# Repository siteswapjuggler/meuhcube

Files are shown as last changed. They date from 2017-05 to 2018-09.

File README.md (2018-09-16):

# The MeuhCube project

The MeuhCube is an Open Source 7x7x7 LED cube project based on Arduino Mega 2560. It aims to provide any needed resources to create your own cube, including the electronic schematics, a laser cutted case and the firmware.

A MeuhCube can basically display embedded animations with the Arduino sketch or be driven over USB by any smart device like a computer, a Raspberry Pi or a smartphone.

The Arduino sketch also exposes a serial API over USB that can be implemented by some remote programs.

## What can I find in this repository?

There is some folders categorizing the resources:

  * **hardware:** Contains a bill of materials you'll need to buy, the electronic schematics, a laser cutted case and some 3D printable tools that will help you in you task
  * **software:** Contains the Arduino firmware and a young simulator, all you need to start!

You'll find more informations in the readme file of each folder.

## Remote clients over USB

You can drive a cube over USB with one of the clients in the **software** folder:

  * a Max/MSP sketch
  * a Proccesing library and simulator
  * a Python Module in Progress
  
You can also use this clients under developpement : 
  * [PLFM, a Python library for MeuhCube](https://gitlab.com/influencepc/Python-library-for-MeuhCube)

## External resources

We also post an additionnal documentation of this project in our local Fablab website :

  * 2016-01-15: [[fr] Meuh cube: Cube lumineux 7\*7\*7 Led V1](https://fablab.ledome.info/#!/projects/cube-lumineux-7-7-7-led)
  * 2016-09-01: [[fr] Meuhcube / cube à leds 7\*7\*7 v2](https://fablab.ledome.info/#!/projects/cube-lumineux-7-7-7-led-v2)

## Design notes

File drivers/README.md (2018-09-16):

# The driver folder

This folder contains the driver for the serial USB CH341 chipset used by some low cost Arduino Mega 2560s found on the net.

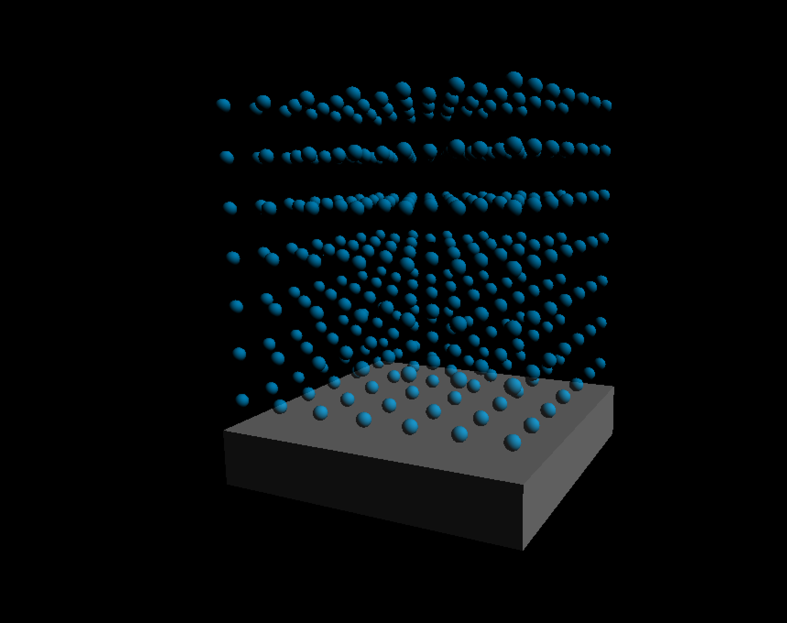
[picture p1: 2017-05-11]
software/processing/Cube simulator/cube_simulator.png

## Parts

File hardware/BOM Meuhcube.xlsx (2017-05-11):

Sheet: BOM
LISTE COMPOSANTS CUBE PCB
ref. Farnell | nom | specs | boitier | prix | nb | note | ou bien
1759415 | C3 | X5R / 6.3V / 22 uF | 0805 | 0.43 € | 1
2496834 | C1 | X7R / 6.3V / 0.1 uF | 0603 | 0.01 € | 1
2376912 | regulateur | ADP23001 | TSOT | 1.25 € | 1
1467689 | comparateur | TS391ILT | SOT-23-5 | 0.36 € | 1
2333955 | inductance | 4.7 uH |  | 0.74 € | 1
1843686 | D1 |  |  | 0.55 € | 1
1170937 | R1 | 31.6k | 0603 | 0.0012 € | 1
1170889 | R2 | 10.2k | 0603 | 0.01 € | 1
 | R3 |  | 603 |  | 7 |  | ????
1471048 | canal N |  |  | 0.15 € | 49
2317568 | transistor |  |  | 0.33 € | 7
2320833 | C2 | X5R / 25V / 10 uF | 0805 | 0.33 € | 1
1593494 | connecteur | 20 pin / femelle |  | 1.80 € | 1 |  | 1593503
2356147 | connecteur | 36 pin / male |  | 2.10 € | 1
2356160 | connecteur | 8 pin / male |  | 0.45 € | 5
1841229 | connecteur | 10 pin / male |  | 0.54 € | 1
1800872 | pieds | 3 mm / noir |  | 0.15 € | 4
- | PCB |  |  | 21.12 € | 1
 |  |  |  | 41.94 €
R2 - 3.1V | 9330453
R2 - 3V | 1170894

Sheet: Ports
PORT CONFIGURATION - 56 ports nécessaires pour les leds
D | A | USAGE | X | Y | Z
- | - | 3v3 |  |  |  | 22 ports à faire remonter
- | - | 5v
- | - | AREF
- | - | GND
- | - | IOREF
- | - | RESET
- | - | Vin
47 |  |  | 0 |  | 0
69 | 15 |  | 0 |  | 1
67 | 13 |  | 0 |  | 2
65 | 11 |  | 0 |  | 3
66 | 12 |  | 0 |  | 4
58 | 4 |  | 0 |  | 5
57 | 3 |  | 0 |  | 6
43 |  |  | 1 |  | 0
68 | 14 |  | 1 |  | 1
64 | 10 |  | 1 |  | 2
63 | 9 |  | 1 |  | 3
56 | 2 |  | 1 |  | 4
55 | 1 |  | 1 |  | 5
54 | 0 |  | 1 |  | 6
41 |  |  | 2 |  | 0
29 |  |  | 2 |  | 1
53 |  | SS
52 |  | SCK
51 |  | MOSI
50 |  | MISO
61 | 7 |  | 2 |  | 2
60 | 6 |  | 2 |  | 3
59 | 5 |  | 2 |  | 4
62 | 8 |  | 2 |  | 5
44 |  |  | 2 |  | 6
39 |  |  | 3 |  | 0
27 |  |  | 3 |  | 1
36 |  |  | 3 |  | 2
38 |  |  | 3 |  | 3
40 |  |  | 3 |  | 4
42 |  |  | 3 |  | 5
34 |  |  | 3 |  | 6
35 |  |  | 4 |  | 0
25 |  |  | 4 |  | 1
24 |  |  | 4 |  | 2
26 |  |  | 4 |  | 3
28 |  |  | 4 |  | 4
30 |  |  | 4 |  | 5
32 |  |  | 4 |  | 6
37 |  |  | 5 |  | 0
22 |  |  | 5 |  | 1
2 |  |  | 5 |  | 2
4 |  |  | 5 |  | 3
6 |  |  | 5 |  | 4
8 |  |  | 5 |  | 5
13 |  |  | 5 |  | 6
33 |  |  | 6 |  | 0
23 |  |  | 6 |  | 1
21 |  | SCL
20 |  | SDA
19 |  | RX1
18 |  | TX1
17 |  | RX2
16 |  | TX2
15 |  | RX3
14 |  | TX3
3 |  |  | 6 |  | 2
5 |  |  | 6 |  | 3
7 |  |  | 6 |  | 4
9 |  |  | 6 |  | 5
10 |  |  | 6 |  | 6
49 |  |  |  | 0
45 |  |  |  | 1
48 |  |  |  | 2
46 |  |  |  | 3
12 |  |  |  | 4
11 |  |  |  | 5
31 |  |  |  | 6
1 |  | TX0
0 |  | RX0

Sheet: Calcul régulateur
V out | R1/R2
2.9 | 2.625 |  | 3.098039216
 |  | 31.6 | 10.2 | 3.098039216
 |  | 31.6 | 11 | 2.872727273
 |  | 31.6 | 11.5 | 2.747826087
 |  | 31.6 | 10.2 | 3.098039216
 |  | 31.6 | 10.2 | 3.098039216
 |  | 31.6 | 10.2 | 3.098039216
 |  | 31.6 | 10.2 | 3.098039216
 |  | 31.6 | 10.2 | 3.098039216
 |  | 31.6 | 10.2 | 3.098039216
 |  | 31.6 | 10.2 | 3.098039216
 |  | 31.6 | 10.2 | 3.098039216
 |  | 31.6 | 10.2 | 3.098039216
 |  | 31.6 | 10.2 | 3.098039216

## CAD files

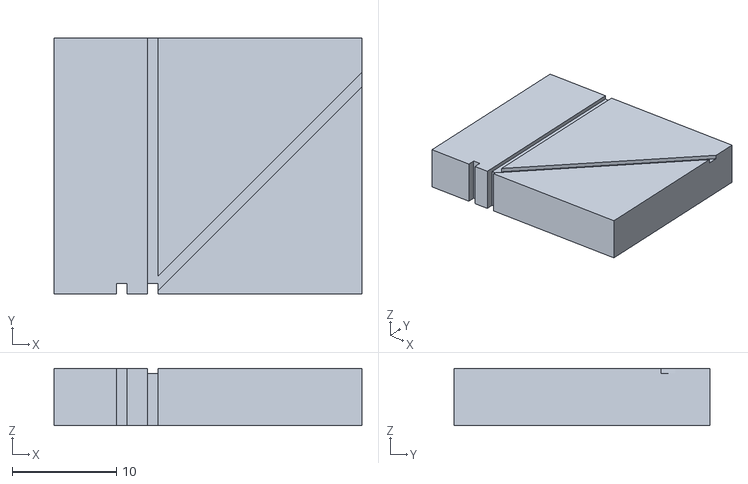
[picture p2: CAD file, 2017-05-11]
hardware/STL prints/1 x plieur_led2.stl
29.6 x 24.6 x 5.50

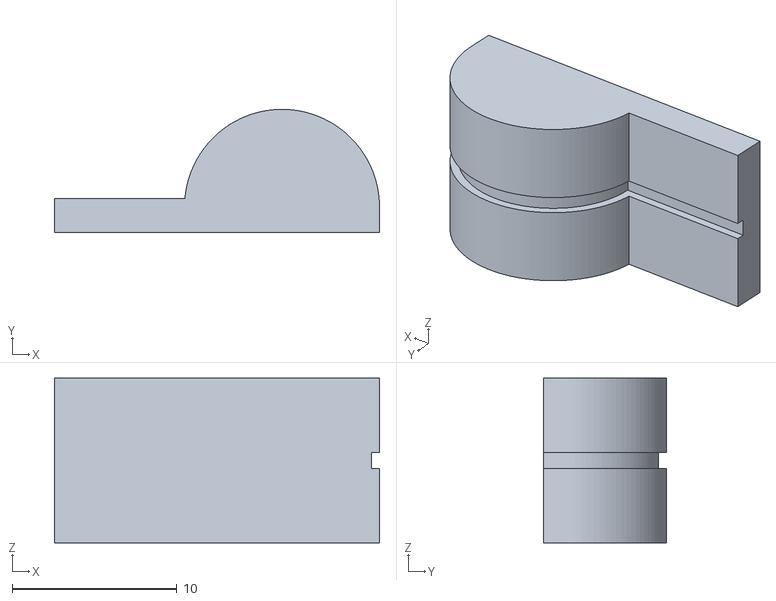
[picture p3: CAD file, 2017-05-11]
hardware/STL prints/1 x rond_led2_10mm.stl
19.7 x 7.48 x 10.0

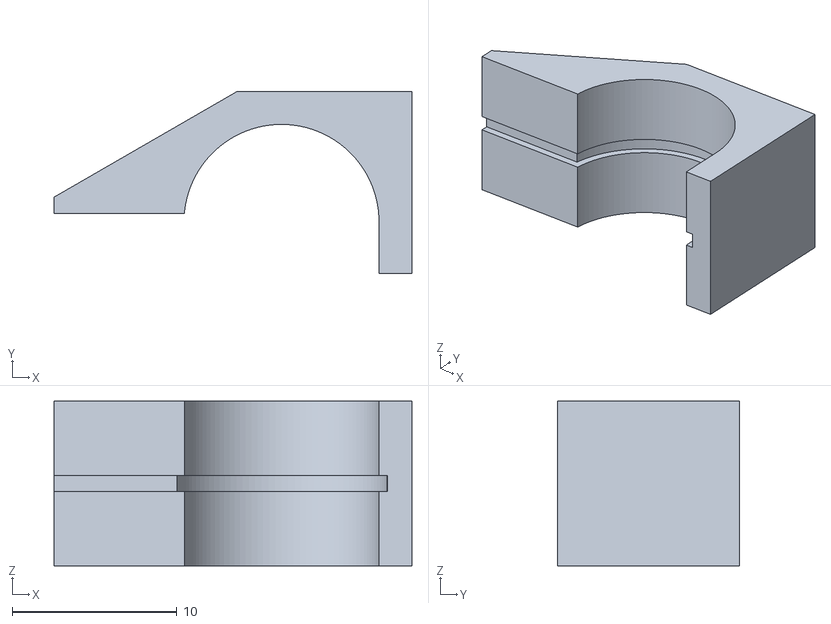
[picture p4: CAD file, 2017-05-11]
hardware/STL prints/1 x rond_led1_10mm.stl
21.7 x 11.0 x 10.0

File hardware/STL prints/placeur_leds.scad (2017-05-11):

nbled = 7;
ecart = 16.5;
fil   = 0.5;
depth = 3;

linear_extrude(height = depth)
difference() {  
    square([nbled*ecart,ecart+fil]);

for (i = [1:nbled]) {
    translate([i*ecart - ecart/2 - fil,0,0]) 
    square([fil*2,fil*2]);
  }

for (i = [1:nbled]) {
    translate([i*ecart - ecart/2 - fil,ecart-fil*2,0]) 
    square([fil*2,fil*2]); 
  }

for (i = [1:nbled-1]) {
    translate([i*ecart-depth/2,0,0]) 
    square([depth,ecart/2]); 
  }  
 }

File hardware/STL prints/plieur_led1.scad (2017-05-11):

ecart   = 4;
hauteur = 5;
epais   = 1;
profondeur = 20;
largeur = 16.5;


difference() {
    cube([largeur*1.4,profondeur,hauteur+epais/2]);
    translate([largeur/2-ecart/2,3,0]) cylinder(10,0.5,0.5);
    translate([largeur/2+ecart/2,3,0]) cylinder(10,0.5,0.5);
    translate([largeur/2+ecart/2-epais/2,3,hauteur]) cube([epais,profondeur,epais]);
    translate([largeur/2+ecart/2,3,hauteur]) 
    rotate([0,0,-45])
    translate([-epais/2,0,0])
    cube([epais,profondeur,epais]);
}

/*

pi    = 3.14;
anode = 25;
ecart = 16.5;
marge = 3;
rayon = (marge+anode-ecart)/pi;
diam  = 2*rayon;
echo(diam);

$fn = 100;

//negatif();
//positif();
//fil();

module negatif() {
    difference() {
        cube([ecart-marge+2*rayon+2,6,10]);
        translate([0,4,0])
        rotate([0,0,10])
        cube([ecart-marge+2*rayon+2,6,10]);
        positif();
        fil();
    }
}

module fil() {
    translate([0,0,5-epais/2])
    union() {
        translate([0,2-epais/2,0])
        cube([ecart-marge,epais,epais]);
        
        translate([rayon-marge+ecart,2-epais/2,0])
        difference() {
            cylinder(epais,rayon+epais/2,rayon+epais/2);
            cylinder(epais,rayon-epais/2,rayon-epais/2);
            translate([0,-ecart/2,0]) cube([ecart,ecart,ecart],center=true);
            }
            
       translate([ecart-marge+2*rayon-epais/2,0,0])
       cube([epais,2-epais/2,epais]);
    }
}

module positif(){
    difference() {
union() {
cube([ecart-marge+2*rayon-epais/8,2,10]);
translate([rayon-marge+ecart,2,0])
difference() {
    translate([0,-epais/2,0])
cylinder(10,rayon,rayon);
translate([0,-ecart/2,ecart/2]) cube([ecart,ecart,ecart],center=true);
}
}
fil();
}
}
*/

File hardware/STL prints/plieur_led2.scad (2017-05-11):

pliure  = 5;        // distance pour la pliure
fil     = 0.5;      // épaisseur des pattes
ecart   = 3;        // écart entre les pattes
anode   = 29.6;     // longueur de l'anode
cathode = 28.1;     // longueur de la cathode
espace  = 16.5;     // espace entre les leds
led     = 5.4;      // auteur de la led


//----------------------------------------------------------------------------------
// ICI C'EST LE PROGRAMME QUI GÈRE
//----------------------------------------------------------------------------------

//plieur1();

module plieur1() {
    difference() {
        // masse principale
        cube([anode,anode+2*ecart-pliure,pliure+fil]);
        
        // passage pattes verticale
        translate([ecart*2,ecart*2,0]) cube([fil*2,fil*2,10]);;
        translate([ecart*3,ecart*2,0]) cube([fil*2,fil*2,10]);;
        
        // guide pattes horizontales
        translate([ecart*3,ecart*2,pliure]) 
        cube([fil*2,anode-pliure,fil*2]);

        // guide pattes diagonale
        translate([ecart*3,ecart*2,pliure]) 
        rotate([0,0,-45])
        translate([-fil,fil,0])
        cube([fil*2,anode,fil*2]);
     }
 }
 
 module plieur2() {
    difference() {
        // masse principale
        cube([anode,anode+2*ecart-pliure,pliure+fil]);
        
        // passage pattes verticale
        translate([ecart*2,ecart*2,0]) cube([fil*2,fil*2,10]);;
        translate([ecart*3,ecart*2,0]) cube([fil*2,fil*2,10]);;
        
        // guide pattes horizontales
        translate([ecart*3,ecart*2,pliure]) 
        cube([fil*2,anode-pliure,fil*2]);

        // guide pattes diagonale
        translate([ecart*3,ecart*2,pliure]) 
        rotate([0,0,-45])
        translate([-fil,fil,0])
        cube([fil*2,anode,fil*2]);
        
        // coupe 
        cube([anode,2*ecart,pliure+fil]);
     }
 }
 

pi    = 3.14159265359;
marge = 3.13363;
rayon = (anode-marge-espace+led/2)/(pi-1);
reste =  espace - rayon - led/2;
epais = 10;

$fn = 100;

negatif();
//positif();
//fil();
 

module negatif() {
    difference() {
        translate([0,-marge-fil,-epais/2])
        cube([reste+2*rayon+4*fil,rayon+4*fil+marge,epais]);
        translate([0,-2*marge-fil,-epais/2])
        cube([reste+2*rayon,2*marge,epais]);
        translate([0,1,-epais/2])
        rotate([0,0,30])
        cube([anode,2*marge,epais]);
        positif();
        fil();
    }
}

module fil() {
    translate([0,-fil,-fil])
    union() {
        // partie principale
        cube([reste,fil*2,fil*2]);
        
        // partie arrondie
        translate([reste+rayon,0,0])
        difference() {
            cylinder(fil*2,rayon+fil,rayon+fil);    
            cylinder(fil*2,rayon-fil,rayon-fil);
            translate([-rayon-fil,-rayon-fil,0])
            cube([2*(rayon+fil),rayon+fil,2*fil]);
            }
       
            
       // marge pour accroche
       translate([reste+2*rayon-fil,-marge,0])
       cube([2*fil,marge,fil*2]);
    }
}

module positif(){
    difference() {
    translate([0,0,-epais/2])
    difference() {
        union() {
            translate([0,-marge-fil,0])
            cube([reste+rayon,marge+fil,epais]);
            translate([reste+rayon,-marge-2*fil,0])
            cube([rayon,marge+fil,epais]);
            translate([reste+rayon,-fil,0])
            cylinder(epais,rayon,rayon);
        }
        translate([0,-2.5*marge-fil,0])
        cube([reste+2*rayon,2*marge,epais]);
    }
    fil();
    }
}

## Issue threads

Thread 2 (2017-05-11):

Create a SDK to allow developers to start testing and create things without the need a personal cube

Vincent14, 2017-05-11:
I would create a backlog to list the ideas that could be useful for the project' SDK. Feel free to contribute :)

Two options
- Use an Arduino simulator to run the sketch on PC and develop the corresponding LED matrix to display outputs
- Rewrite a serial listener copying the messages' unpacker in the Arduino sketch, then develop the corresponding LED matrix to display outputs

siteswapjuggler, 2017-06-18:
The developpement of an SDK would be usefull for a commercial or a large scale product. Even if it would be even manageable to rightfully simulate the arduino and the electronical attached to it.

Two simulation have been started so far, the max/msp patch wich could animate a 3D matrix of 343 boolean value and translate it into a compatible serial message to the cube. And the processing librairy which could be easily continuated to simulate the cube on screen and/or send the commands to the real cube.

Closed 2017-06-18.

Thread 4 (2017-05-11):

Move USB clients in others git repositories

Vincent14, 2017-05-11:
It could be interesting to split git repositories by projects. This repo could store anything needed to have a functional LED cube (bom, hardware parts, firmware). I added the Python library to the main readme in one of my pull requests, we could list all clients there and let people contribute to them. It's only project management, but give more clarity in my opinion.

Example:

  * move software/max-msp folder to another repository
  * let software/processing simulator, move remote example to another repository

siteswapjuggler, 2017-06-18:
The repositories represent a small scale hobbyist project no need to make it over complicated. The examples provided are simple and light weight. I intend to let them is this repository.

Closed 2017-06-18.

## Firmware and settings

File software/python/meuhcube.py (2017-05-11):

"""
Copyright Vincent LAMBERT. (2016)
email: vincent@influence-pc.fr
This software is a computer program whose purpose is to give access to an API over serial connexion to a device called Meuhcube. The Meuhcube is a Do-It-Yourself project using the Arduino Mega to drive a 7x7x7 LED cube.
This software is governed by the CeCILL license under French law and abiding by the rules of distribution of free software.  You can  use, modify and/ or redistribute the software under the terms of the CeCILL license as circulated by CEA, CNRS and INRIA at the following URL "http://www.cecill.info".
As a counterpart to the access to the source code and rights to copy, modify and redistribute granted by the license, users are provided only with a limited warranty  and the software's author,  the holder of the economic rights, and the successive licensors  have only  limited liability.
In this respect, the user's attention is drawn to the risks associated with loading,  using,  modifying and/or developing or reproducing the software by the user in light of its specific status of free software, that may mean  that it is complicated to manipulate,  and  that  also therefore means  that it is reserved for developers  and  experienced professionals having in-depth computer knowledge. Users are therefore encouraged to load and test the software's suitability as regards their requirements in conditions enabling the security of their systems and/or data to be ensured and,  more generally, to use and operate it in the same conditions as regards security.
The fact that you are presently reading this means that you have had knowledge of the CeCILL license and that you accept its terms.
"""

#!/usr/bin/python
# -*- coding: utf-8 -*-

import sys
import glob
import serial
import time


def serial_ports():
  """
  Lists serial port names
  """
  if sys.platform.startswith('win'):
    ports = ['COM%s' % (i + 1) for i in range(256)]
  elif sys.platform.startswith('linux') or sys.platform.startswith('cygwin'):
    # this excludes your current terminal "/dev/tty"
    ports = glob.glob('/dev/tty[A-Za-z]*')
  elif sys.platform.startswith('darwin'):
    ports = glob.glob('/dev/tty.wc*')
  else:
    raise EnvironmentError('Unsupported platform')

  result = []
  for port in ports:
    try:
      s = serial.Serial(port)
      s.close()
      result.append(port)
    except (OSError, serial.SerialException):
     pass
  return result


# Commands to turn on/off LED

def set_all(layer_states = 7 * [True]):
  """
  Turn all LED on without parameter. Turn layers on if a list of seven bits is given, from right to left. Parameter:
  - layer_states, a list of seven booleans
  Example: (False, False, False, False, True, False, True) will turn off all LED of layers 7, 6, 5, 4, 2 and turn on LED of layers 3 and 1
  """
  int_states = [int(boolean) for boolean in layer_states]
  str_states = [str(boolean) for boolean in int_states]
  str_states.reverse() # bit parameters are from left to right
  bits = "".join(str_states)
  byte = int(bits, 2)
  usb_link.write(bytearray([0xE7, 0x00, 0x01, byte, 0x7E]))


def set_voxel(coordinates = [0, 0, 0], led_state = True):
  """
  Turn a voxel on. Parameters:
  - coordinates, an integer list for x, y, z
  - led_state, a boolean
  """
  usb_link.write(bytearray([0xE7, 0x01, 0x04, coordinates[0], coordinates[1], coordinates[2], int(led_state), 0x7E]))


def set_line(axis = "x", shift_side_1 = 0, shift_side_2 = 0, led_states = 7 * [True]):
  """
  Turn a line on. Parameters:
  - axis, chose an edge of the cube as reference. A string of "x", "y" or "z"
  - shift_side_1, shift the line from the chosen axis to one of the two adjacent sides. An integer between 0 and 6
  - shift_side_2, shift the line from the chosen axis to one of the two adjacent sides. An integer between 0 and 6
  - led_states, seven booleans
  """
  if axis == "x":
    axis_byte = 0
  elif axis == "y":
    axis_byte = 1
  elif axis == "z":
    axis_byte = 2
  int_states = [int(boolean) for boolean in led_states]
  str_states = [str(boolean) for boolean in int_states]
  str_states.reverse() # bit parameters are from left to right
  bits = "".join(str_states)
  state_byte = int(bits, 2)
  usb_link.write(bytearray([0xE7, 0x02, 0x04, axis_byte, shift_side_1, shift_side_2, state_byte, 0x7E]))


def set_plan(axis = "xy", shift = 0, led_states = 7 * [True]):
  """
  Turn a plan on, by a line or pixel by pixel, depending of the led_states parameter.
  """
  if type(led_states[0]) is bool:
    set_plan_by_line(axis, shift, led_states)
  else:
    set_plan_by_pixel(axis, shift, led_states)


def set_plan_by_line(axis = "xy", shift = 0, led_states = 7 * [True]):
  """
  Turn a plan on. The columns of the plan are defined by a single line replicated on the seven columns. Parameters:
  - axis, chose two axis letters to select a side of the cube. A string of "xy", "xz" or "yz"
  - shift, move the plan from a side of the cube into it. An integer between 0 and 6
  - led_states, seven booleans figuring a line used on the seven columns of the plan
  """
  if axis == "xz":
    axis_byte = 0
  elif axis == "xy":
    axis_byte = 1
  elif axis == "yz":
    axis_byte = 2
  int_states = [int(boolean) for boolean in led_states]
  str_states = [str(boolean) for boolean in int_states]
  str_states.reverse() # bit parameters are from left to right
  bits = "".join(str_states)
  state_byte = int(bits, 2)
  usb_link.write(bytearray([0xE7, 0x03, 0x03, axis_byte, shift, state_byte, 0x7E]))


def set_plan_by_pixel(axis = "xy", shift = 0, led_states = 7 * [7 * [True]]):
  """
  Turn a plan on. The columns of the plan are defined pixel by pixel. Parameters:
  - axis, chose two axis letters to select a side of the cube. A string of "xy", "xz" or "yz"
  - shift, move the plan from a side of the cube into it. An integer between 0 and 6
  - led_states, seven arrays of seven booleans to define the plan pixel by pixel
  """
  if axis == "xz":
    axis_byte = 0
  elif axis == "xy":
    axis_byte = 1
  elif axis == "yz":
    axis_byte = 2
  state_bytes = []
  for i in range(7):
    int_states = [int(boolean) for boolean in led_states[i]]
    str_states = [str(boolean) for boolean in int_states]
    str_states.reverse() # bit parameters are from left to right
    bits = "".join(str_states)
    state_bytes.append(int(bits, 2))
  usb_link.write(bytearray([0xE7, 0x03, 0x09, axis_byte, shift, state_bytes[0], state_bytes[1], state_bytes[2], state_bytes[3], state_bytes[4], state_bytes[5], state_bytes[6], 0x7E]))


def set_cube(led_states = 7 * [7 * [7 * [True]]]):
  """
  Turn the whole cube on, led by led. Parameters:
  - led_states, seven arrays of seven arrays of seven booleans, to define each voxel
  """
  state_bytes = []
  for i in range(7):
    for j in range(7):
      int_states = [int(boolean) for boolean in led_states[i][j]]
      str_states = [str(boolean) for boolean in int_states]
      str_states.reverse() # bit parameters are from left to right
      bits = "".join(str_states)
      state_bytes.append(int(bits, 2))
  usb_link.write(bytearray([0xE7, 0x04, 0x31] + state_bytes + [0x7E]))


# Commands to reverse the LED states

def rev_all():
  """
  Reverse current state of whole cube
  """
  usb_link.write(bytearray([0xE7, 0x10, 0x00, 0x7E]))


def rev_voxel(coordinates = [0, 0, 0]):
  """
  Reverse a voxel state. Parameters:
  - coordinates, an integer list for x, y, z
  """
  usb_link.write(bytearray([0xE7, 0x11, 0x03, coordinates[0], coordinates[1], coordinates[2], 0x7E]))


def rev_line(axis = "x", shift_side_1 = 0, shift_side_2 = 0, led_states = 7 * [True]):
  """
  Turn a line on. Parameters:
  - axis, chose an edge of the cube as reference. A string of "x", "y" or "z"
  - shift_side_1, shift the line from the chosen axis to one of the two adjacent sides. An integer between 0 and 6
  - shift_side_2, shift the line from the chosen axis to one of the two adjacent sides. An integer between 0 and 6
  - led_states, seven booleans
  """
  if axis == "x":
    axis_byte = 0
  elif axis == "y":
    axis_byte = 1
  elif axis == "z":
    axis_byte = 2
  int_states = [int(boolean) for boolean in led_states]
  str_states = [str(boolean) for boolean in int_states]
  str_states.reverse() # bit parameters are from left to right
  bits = "".join(str_states)
  state_byte = int(bits, 2)
  usb_link.write(bytearray([0xE7, 0x12, 0x04, axis_byte, shift_side_1, shift_side_2, state_byte, 0x7E]))


def rev_plan(axis = "xy", shift = 0, led_states = 7 * [True]):
  """
  Turn a plan on, by a line or pixel by pixel, depending of the led_states parameter.
  """
  if type(led_states[0]) is bool:
    rev_plan_by_line(axis, shift, led_states)
  else:
    rev_plan_by_pixel(axis, shift, led_states)


def rev_plan_by_line(axis = "xy", shift = 0, led_states = 7 * [True]):
  """
  Turn a plan on. The columns of the plan are defined by a single line replicated on the seven columns. Parameters:
  - axis, chose two axis letters to select a side of the cube. A string of "xy", "xz" or "yz"
  - shift, move the plan from a side of the cube into it. An integer between 0 and 6
  - led_states, seven booleans figuring a line used on the seven columns of the plan
  """
  if axis == "xz":
    axis_byte = 0
  elif axis == "xy":
    axis_byte = 1
  elif axis == "yz":
    axis_byte = 2
  int_states = [int(boolean) for boolean in led_states]
  str_states = [str(boolean) for boolean in int_states]
  str_states.reverse() # bit parameters are from left to right
  bits = "".join(str_states)
  state_byte = int(bits, 2)
  usb_link.write(bytearray([0xE7, 0x13, 0x03, axis_byte, shift, state_byte, 0x7E]))


def rev_plan_by_pixel(axis = "xy", shift = 0, led_states = 7 * [7 * [True]]):
  """
  Turn a plan on. The columns of the plan are defined pixel by pixel. Parameters:
  - axis, chose two axis letters to select a side of the cube. A string of "xy", "xz" or "yz"
  - shift, move the plan from a side of the cube into it. An integer between 0 and 6
  - led_states, seven booleans figuring a line used on the seven columns of the plan
  """
  if axis == "xz":
    axis_byte = 0
  elif axis == "xy":
    axis_byte = 1
  elif axis == "yz":
    axis_byte = 2
  state_bytes = []
  for i in range(7):
    int_states = [int(boolean) for boolean in led_states[i]]
    str_states = [str(boolean) for boolean in int_states]
    str_states.reverse() # bit parameters are from left to right
    bits = "".join(str_states)
    state_bytes.append(int(bits, 2))
  usb_link.write(bytearray([0xE7, 0x13, 0x09, axis_byte, shift, state_bytes[0], state_bytes[1], state_bytes[2], state_bytes[3], state_bytes[4], state_bytes[5], state_bytes[6], 0x7E]))


def rev_cube(led_states = 7 * [7 * [7 * [True]]]):
  """
  Turn the whole cube on, led by led. Parameters:
  - led_states, seven arrays of seven arrays of seven booleans, to define each voxel
  """
  state_bytes = []
  for i in range(7):
    for j in range(7):
      int_states = [int(boolean) for boolean in led_states[i][j]]
      str_states = [str(boolean) for boolean in int_states]
      str_states.reverse() # bit parameters are from left to right
      bits = "".join(str_states)
      state_bytes.append(int(bits, 2))
  usb_link.write(bytearray([0xE7, 0x14, 0x31] + state_bytes + [0x7E]))


# Animation commands

def translate(axis = "x", step = 1):
  """
  Translate all turned on LED against an axis, optionnaly in steps of more than one LED. Parameters:
  - axis, chose an edge of the cube as reference. A string of "x", "y" or "z"
  - step, an integer between 1 and 7
  """
  move_xyz(axis, step)


def move_xyz(axis = "x", step = 1):
  """
  Translate all turned on LED against an axis, losing the state of LED outside the cube, optionnaly in steps of more than one LED. Parameters:
  - axis, chose an edge of the cube as reference. A string of "x", "y" or "z"
  - step, an integer between 1 and 7
  """
  if axis == "x":
    axis_byte = 0
  elif axis == "y":
    axis_byte = 1
  elif axis == "z":
    axis_byte = 2
  usb_link.write(bytearray([0xE7, 0x21, 0x02, axis_byte, step, 0x7E]))


def modu_xyz(axis = "x", step = 1):
  """
  Translate all turned on LED against an axis, looping on it, optionnaly in steps of more than one LED. Parameters:
  - axis, chose an edge of the cube as reference. A string of "x", "y" or "z"
  - step, an integer between 1 and 7
  """
  if axis == "x":
    axis_byte = 0
  elif axis == "y":
    axis_byte = 1
  elif axis == "z":
    axis_byte = 2
  usb_link.write(bytearray([0xE7, 0x22, 0x02, axis_byte, step, 0x7E]))


def rotate(axis = "x", step = 1):
  rota_xyz(axis, step)


def rota_xyz(axis = "x", step = 1):
  if axis == "x":
    axis_byte = 0
  elif axis == "y":
    axis_byte = 1
  elif axis == "z":
    axis_byte = 2
  usb_link.write(bytearray([0xE7, 0x23, 0x01, axis_byte, 0x7E]))


def mirror(axis = "x", step = 1):
  miro_xyz(axis, step)


def miro_xyz(axis = "x", step = 1):
  if axis == "x":
    axis_byte = 0
  elif axis == "y":
    axis_byte = 1
  elif axis == "z":
    axis_byte = 2
  usb_link.write(bytearray([0xE7, 0x24, 0x01, axis_byte, 0x7E]))


# System commands

def get_version():
  """
  Get the API version
  """
  usb_link.write(bytearray([0xE7, 0xE0, 0x00, 0x7E]))
  return usb_link.readline()


def load_default_parameters():
  """
  Load default parameters for framerate and layerrate
  """
  usb_link.write(bytearray([0xE7, 0xE1, 0x00, 0x7E]))


def load_last_saved_parameters():
  """
  Load last saved parameters from cube memory
  """
  usb_link.write(bytearray([0xE7, 0xE2, 0x00, 0x7E]))


def save_current_parameters():
  """
  Persist the parameters into the cube memory
  """
  usb_link.write(bytearray([0xE7, 0xE3, 0x00, 0x7E]))


# System parameters
# Not yet implemented


# Code execution limited from file
if __name__ == '__main__':
  try:
    print("Connexion on " + serial_ports()[0] + ":")
    usb_link = serial.Serial(serial_ports()[0], 115200)
    print(usb_link.readline())
    print(get_version())
    load_default_parameters()
    save_current_parameters()

    print("Executing tests:")

    # Fixtures
    loops = 5
    duration = 0.5
    state = True
    seven_states = [True, True, True, False, True, False, False]
    fourty_nine_states = [
      [True, True, True, True, True, True, False],
      [True, True, True, True, True, False, False],
      [True, True, True, True, False, False, False],
      [True, True, True, False, False, False, False],
      [True, True, False, False, False, False, False],
      [True, False, False, False, False, False, False],
      [False, False, False, False, False, False, False],
    ]
    full_cube_states = 7 * [fourty_nine_states]

    # Automated tests
    # print('  * set_all()')
    # for _ in range(loops):
    #   set_all()
    #   time.sleep(duration)
    # set_all(7 * [False])

    # print('  * set_all(seven_states)')
    # for _ in range(loops):
    #   set_all(seven_states)
    #   time.sleep(duration)
    # set_all(7 * [False])

    # print('  * set_voxel((1, 1, 1), state)')
    # for _ in range(loops):
    #   set_voxel((1, 1, 1), state)
    #   time.sleep(duration)
    #   state = not state
    # set_all(7 * [False])

    # print('  * set_line("x", 1, 1, seven_states)')
    # for _ in range(loops):
    #   set_line("x", 1, 1, seven_states)
    #   time.sleep(duration)
    # set_all(7 * [False])

    # print('  * set_plan("xz", 1, seven_states)')
    # for _ in range(loops):
    #   set_plan("xz", 1, seven_states)
    #   time.sleep(duration)
    # set_all(7 * [False])

    # print('  * set_plan("xz", 1, fourty_nine_states)')
    # for _ in range(loops):
    #   set_plan("xz", 1, fourty_nine_states)
    #   time.sleep(duration)
    # set_all(7 * [False])

    # print('  * set_cube(full_cube_states)')
    # for _ in range(loops):
    #   set_cube(full_cube_states)
    #   time.sleep(duration)
    # set_all(7 * [False])

    # print('  * rev_all()')
    # for _ in range(loops):
    #   rev_all()
    #   time.sleep(duration)
    # set_all(7 * [False])

    # print('  * rev_voxel((1, 1, 1))')
    # for _ in range(loops):
    #   rev_voxel((1, 1, 1))
    #   time.sleep(duration)
    # set_all(7 * [False])

    # print('  * set_line("x", 1, 1, seven_states)')
    # for _ in range(loops):
    #   set_line("x", 1, 1, seven_states)
    #   time.sleep(duration)
    # set_all(7 * [False])

    # print('  * rev_line("x", 1, 1, seven_states)')
    # for _ in range(loops):
    #   rev_line("x", 1, 1, seven_states)
    #   time.sleep(duration)
    # set_all(7 * [False])

    # print('  * rev_plan("xz", 1, seven_states)')
    # for _ in range(loops):
    #   rev_plan("xz", 1, seven_states)
    #   time.sleep(duration)
    # set_all(7 * [False])

    # print('  * rev_plan("xz", 1, fourty_nine_states)')
    # for _ in range(loops):
    #   rev_plan("xz", 1, fourty_nine_states)
    #   time.sleep(duration)
    # set_all(7 * [False])

    # print('  * rev_cube(full_cube_states)')
    # for _ in range(loops):
    #   rev_cube(full_cube_states)
    #   time.sleep(duration)
    # set_all(7 * [False])

    # print('  * translate("y")')
    # set_plan("xz", 1, seven_states)
    # for _ in range(loops):
    #   translate("y")
    #   time.sleep(duration)
    # set_all(7 * [False])

    print('  * rotate("z")')
    set_plan("xz", 1, seven_states)
    for _ in range(loops):
      rotate("z")
      time.sleep(duration)
    set_all(7 * [False])

    print('  * mirror("z")')
    set_plan("xz", 1, seven_states)
    for _ in range(loops):
      mirror("z")
      time.sleep(duration)
    set_all(7 * [False])

    print("Tests completed")
  except IndexError:
    print("USB connexion not available.")

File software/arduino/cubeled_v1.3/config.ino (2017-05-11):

//------------------------------------------
// configuration des pattes
//------------------------------------------

#if (VERSION == 0)
const int zPins[SIZE] = { 55, 56, 57, 58, 59, 60, 61 };
const int xyPins[SIZE][SIZE] = {
  { 53, 2, 3, 62, 5, 52, 7 },      // ligneA
  { 8, 9, 10, 11, 12, 13, 14 },    // ligneB
  { 15, 16, 17, 18, 19, 20, 21 },  // ligneC
  { 22, 23, 24, 25, 26, 27, 28 },  // ligneD
  { 29, 30, 31, 32, 33, 34, 35 },  // ligneE
  { 36, 37, 38, 39, 40, 41, 42 },  // ligneF
  { 43, 44, 45, 46, 47, 48, 49 }   // ligneG
};
#else
const int zPins[SIZE] = { 49, 45, 48, 46, 12, 11, 31 };
const int xyPins[SIZE][SIZE] = {
  { 47, 69, 67, 65, 66, 58, 57 },  // X0
  { 43, 68, 64, 63, 56, 55, 54 },  // X1
  { 41, 29, 61, 60, 59, 62, 44 },  // X2
  { 39, 27, 36, 38, 40, 42, 34 },  // X3
  { 35, 25, 24, 26, 28, 30, 32 },  // X4
  { 37, 22,  2,  4,  6,  8, 13 },  // X5
  { 33, 23,  3,  5,  7,  9, 10 }   // X6
};
#endif

const byte mask = 0xFF >> (8 - SIZE); // mask pour éviter les bits perdus

//------------------------------------------
// INTIALISATIONS
//------------------------------------------

void cubeBegin() {
  // Set layers
  for (int layer = 0; layer < SIZE; layer++) {
    pinMode(zPins[layer], OUTPUT);
    digitalWrite(zPins[layer], LOW);
  }

  // Set columns
  for (int x = 0; x < SIZE; x++) {
    for (int y = 0; y < SIZE; y++) {
      pinMode(xyPins[x][y], OUTPUT);
      digitalWrite (xyPins[x][y], LOW);
    }
  }
}

void initLeds() {
  for (int x = 0; x < SIZE; x++) {
    for (int y = 0; y < SIZE; y++) {
      bufferFrame[x][y] = 0;
    }
  }
}

//------------------------------------------
// AFFICHAGE
//------------------------------------------

void refreshFrame() {
  //TODO ici mode automatique
  copyFrame(bufferFrame, actualFrame);
  changed = false;
}

void drawLeds() {
  digitalWrite(zPins[currentLayer], LOW);     // cut the layer before going to the next one.
  currentLayer++;
  currentLayer %= SIZE;

  // Refresh columns for the current Layer
  for (int x = 0; x < SIZE; x++) {
    for (int y = 0; y < SIZE; y++) {
      digitalWrite (xyPins[x][y], bitRead(actualFrame[x][y], currentLayer));
    }
  }

  digitalWrite(zPins[currentLayer], HIGH);    // display the layer.
}

//------------------------------------------
// UTILITAIRES
//------------------------------------------

void testLeds() {
  for (int x = 0; x < SIZE; x++) {
    for (int y = 0; y < SIZE; y++) {
      bufferFrame[x][y] = mask;
    }
  }
  changed = true;
}

void copyFrame(byte source[][SIZE], byte destination[][SIZE]) {
  for (int x = 0; x < SIZE; x++) {
    for (int y = 0; y < SIZE; y++) {
      destination[x][y] = source[x][y];
    }
  }
}

bool demo() {
  pinMode(20,INPUT_PULLUP);
  pinMode(21,INPUT_PULLUP);
  delay(5);
  return !digitalRead(20) | !digitalRead(21);
}

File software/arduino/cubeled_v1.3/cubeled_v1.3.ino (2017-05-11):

/*
   CUBE 7x7x7 - version 1.3
   by Sylvain Garnavault, Luc Bénéchet, Vincent Lambert, Kévin le Déroff

*/

#define VERSION 1                 // version 0 pour le cube de Luc, version 1 pour le Meuhcube
#define SIZE 7

//------------------------------------------
// VARIABLES GLOBALES
//------------------------------------------

byte actualFrame[SIZE][SIZE];       // stocke les valeurs à afficher
byte bufferFrame[SIZE][SIZE];       // prépare les valeurs à afficher
byte currentLayer = 0;              // variable pour global qui stocke la couche à afficher

//----------------------------------------
// VARIABLES
//----------------------------------------

bool changed = false;             // booléen qui indique si buffer a été modifié depuis dernier affichage
bool modedem = false;             // booléen qui détermine si on est en mode démo
long elapsed = 0;                 // time control for refreshing
long pTime   = 0;                 // time control for demo mode
int  compteur = 0;                // pour le mode demo

bool refresh;                     // booléen qui indique si on utilise un rafraichissement externe ou automatique
byte interFrame;                  // time in millis seconds beetween 2 frame drawing
int  interLayer;                  // time in micros seconds beetween 2 layers activations

//----------------------------------------
// INITIALISATION
//----------------------------------------

void setup() {
  Serial.begin(115200);
  Serial.println("Meuhcube online");

#if (VERSION == 0)
  modedem = demo();
  Serial.println(modedem ? "Mode Demo : ON" : "Mode Demo : OFF");
#endif

  cubeBegin();
  initLeds();
  loadParams();
  
  //testLeds();
}

//----------------------------------------
// BOUCLE PRINCIPALE
//----------------------------------------

void loop() {
  if (refresh && changed) refreshFrame();

  if (interLayer) {
    long t = micros();
    if (t - elapsed >= interLayer) {
      drawLeds();
      elapsed = t;
    }
  }
  else drawLeds();

  if (modedem && (millis() - pTime > 50)) {
    compteur++;
    if (compteur < 100) {
      byte x = random(7);
      byte y = random(7);
      byte z = random(7);
      bitWrite(actualFrame[x][y], z, 1);
    }
    else if (compteur < 200) {
      byte x = random(7);
      byte y = random(7);
      byte z = random(7);
      bitWrite(actualFrame[x][y], z, 0);
    }
    else {
      compteur = 0;
    }
    pTime = millis();
  }
}

//----------------------------------------
// GESTION DES EVENEMENTS SERIE
//----------------------------------------

void serialEvent() {
  if (!modedem) {
    while (Serial.available()) {
      byte input = Serial.read();
      parse(input);
    }
  }
}

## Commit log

2017-05-11 First commit
    licence CC-BY-SA
    [1 x plieur_led2.stl, 1 x rond_led1_10mm.stl, 1 x rond_led2_10mm.stl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]
2017-05-11 Documentation
    CC-BY-SA
    [pinout_meuhcube.xlsx]
2018-09-16 licence and cleanup
    [pinout_meuhcube.xlsx]
